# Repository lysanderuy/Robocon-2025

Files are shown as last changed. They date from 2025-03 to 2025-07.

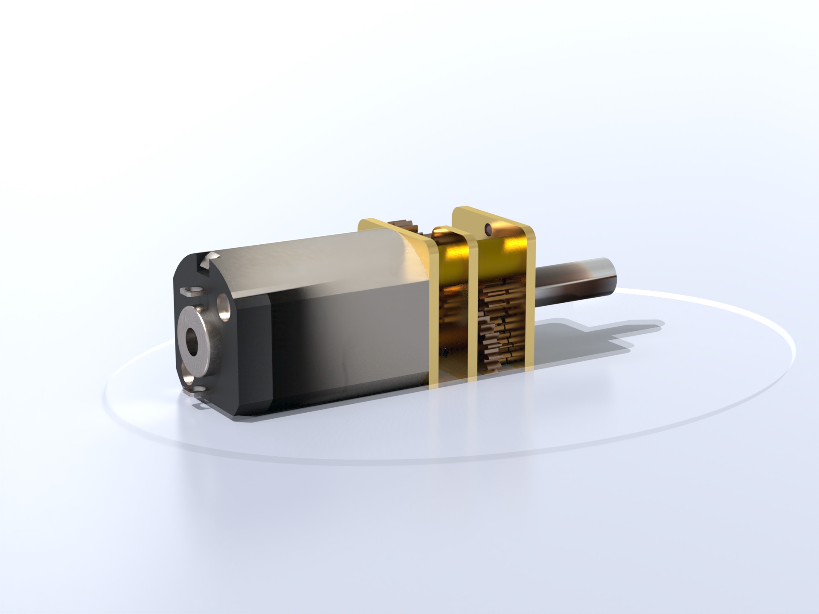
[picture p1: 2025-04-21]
Hardware/3D Parts/Resources/N20/Frame000030.jpg

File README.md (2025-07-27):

USC Robocon-2025 - Robotics Competition (Line Following)

3a6d7730-8ca0-4b9e-8f9a-050f49969c4d
ca18deb3-35a7-4179-8dc5-667313551d99
816b7f0a-6069-4234-8627-e5fa5dca911e

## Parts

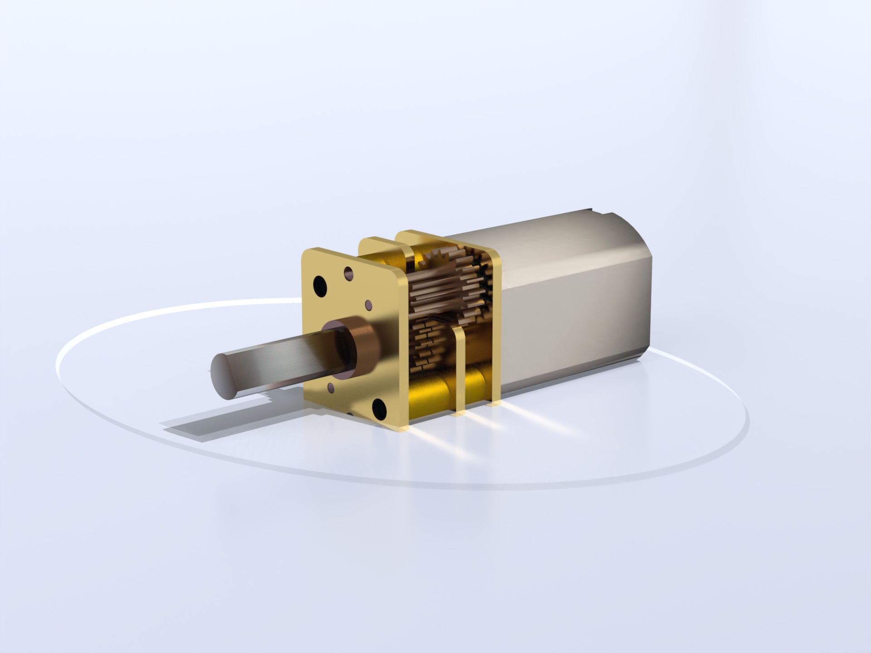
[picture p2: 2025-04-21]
Hardware/3D Parts/Resources/N20/Frame000005.jpg

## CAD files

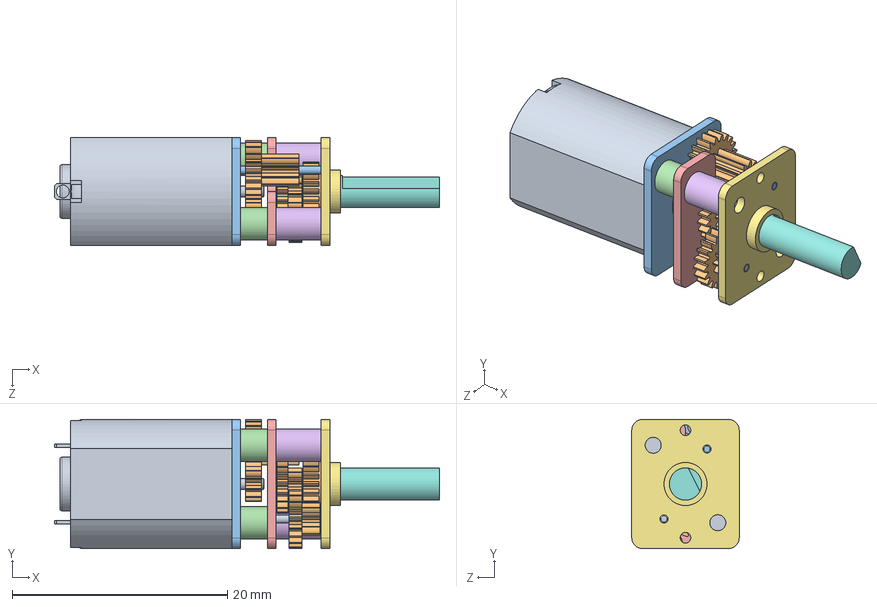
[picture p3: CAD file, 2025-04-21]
Hardware/3D Parts/Resources/N20/Мотор с шестеней.SLDASM
35.8 x 12.0 x 10.0 mm
мотор
spur gear_iso x 8
нижняя пластина редуктора
малая фтулка x 2
средняя пластина редуктора
большая фтулка x 2
верхняя пластина редуктора
вал
втулка шестерни
втулка центральной шестерни
втулка боковой шестерни

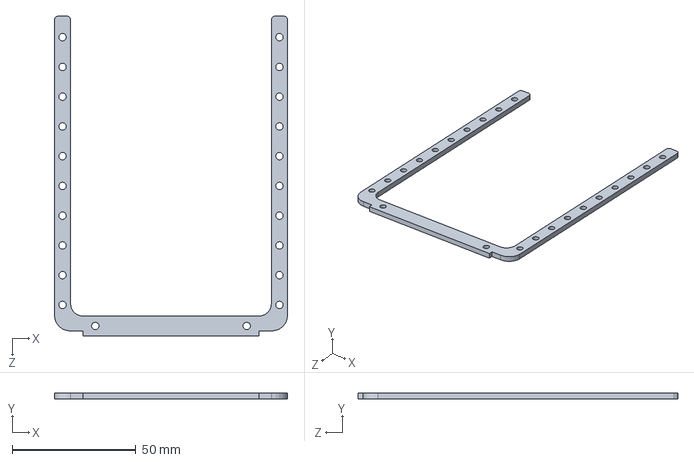
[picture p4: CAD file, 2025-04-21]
Hardware/3D Parts/Mount Rack/mountRack_v1.1.SLDPRT
94.0 x 2.50 x 129.0 mm

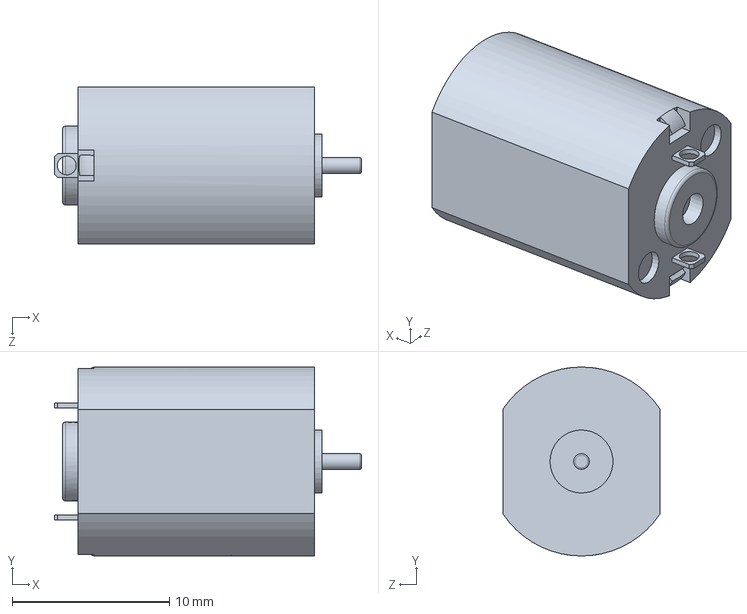
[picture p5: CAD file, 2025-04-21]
Hardware/3D Parts/Resources/N20/мотор.SLDPRT
19.5 x 12.0 x 10.0 mm

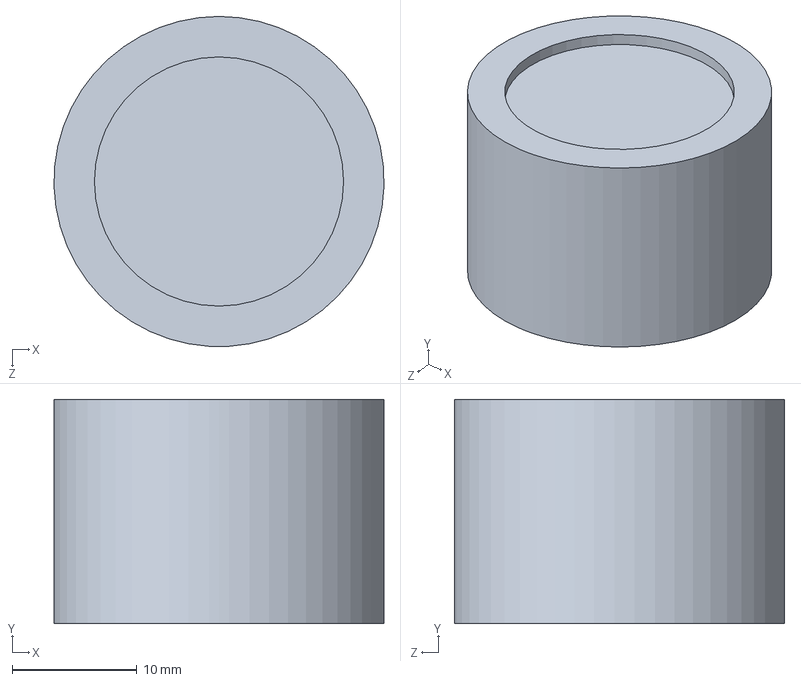
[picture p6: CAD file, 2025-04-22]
Hardware/3D Parts/Wheel/chassisWheel_DHole.SLDPRT
26.5 x 18.0 x 26.5 mm

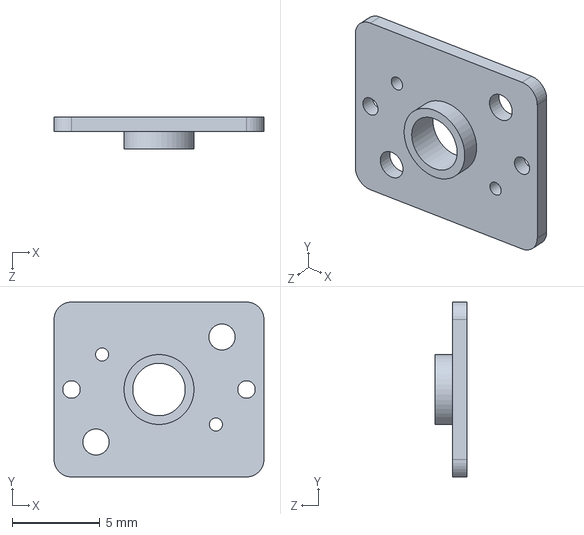
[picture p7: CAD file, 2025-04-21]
Hardware/3D Parts/Resources/N20/верхняя пластина редуктора.SLDPRT
12.0 x 10.0 x 1.80 mm

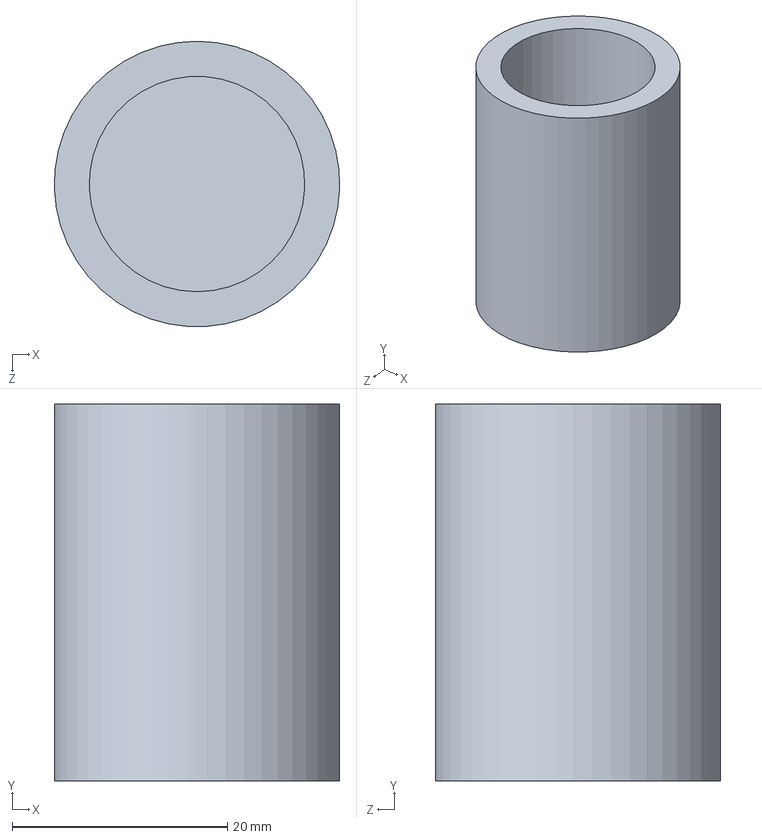
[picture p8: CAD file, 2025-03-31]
Hardware/3D Parts/Wheel/chassisWheel_OHole.SLDPRT
26.5 x 35.0 x 26.5 mm

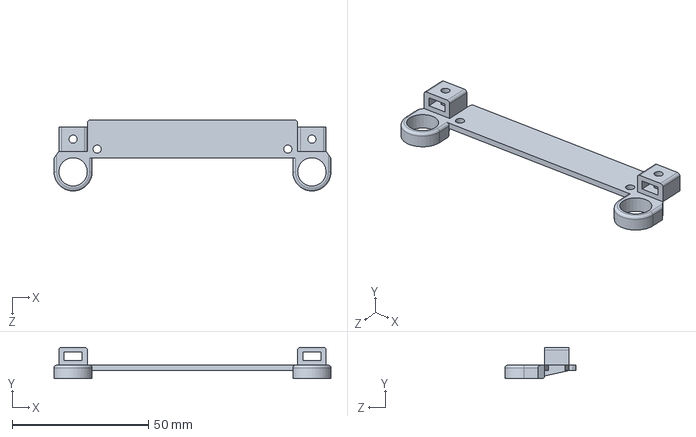
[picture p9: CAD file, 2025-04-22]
Hardware/3D Parts/Mount/sensorcaster_Mount_v1.4.SLDPRT
101.5 x 11.5 x 26.0 mm

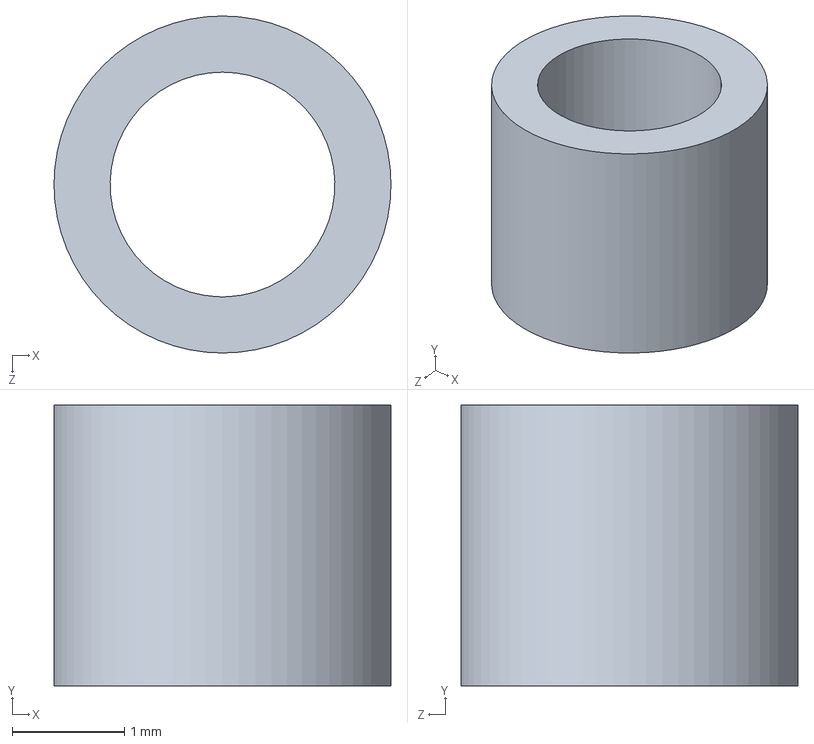
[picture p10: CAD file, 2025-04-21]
Hardware/3D Parts/Resources/N20/малая фтулка.SLDPRT
3.00 x 2.50 x 3.00 mm

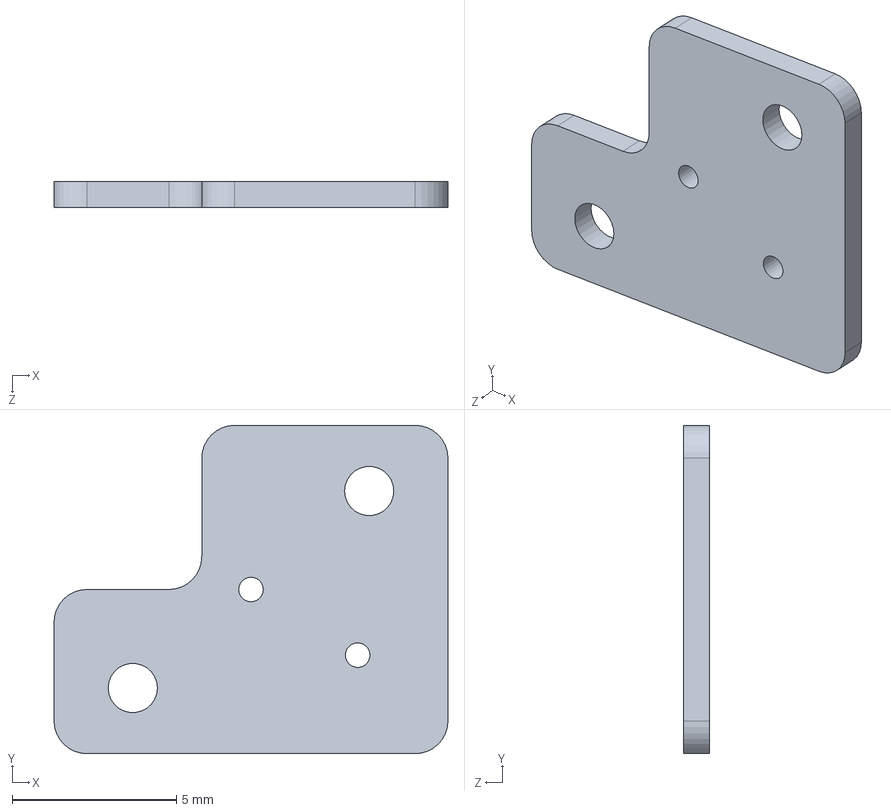
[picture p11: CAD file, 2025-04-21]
Hardware/3D Parts/Resources/N20/средняя пластина редуктора.SLDPRT
12.0 x 10.0 x 0.8 mm

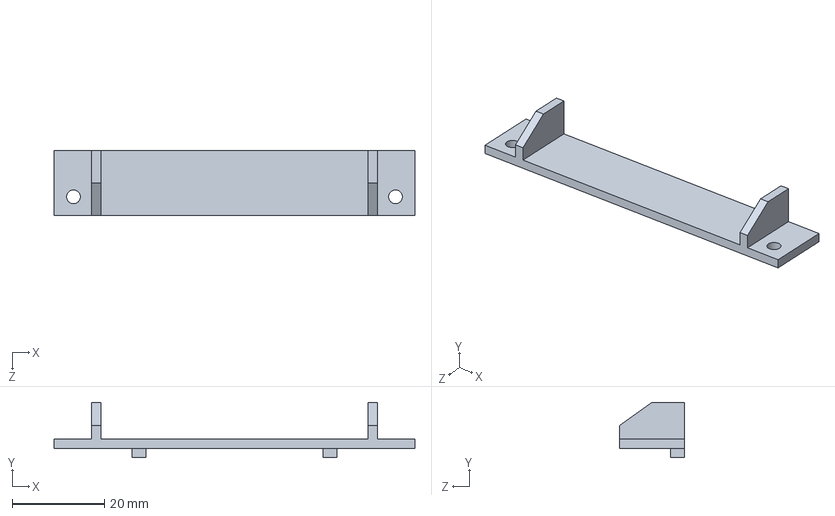
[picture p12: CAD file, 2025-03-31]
Hardware/3D Parts/Mount/sensorHolder.SLDPRT
78.3 x 12.0 x 14.0 mm

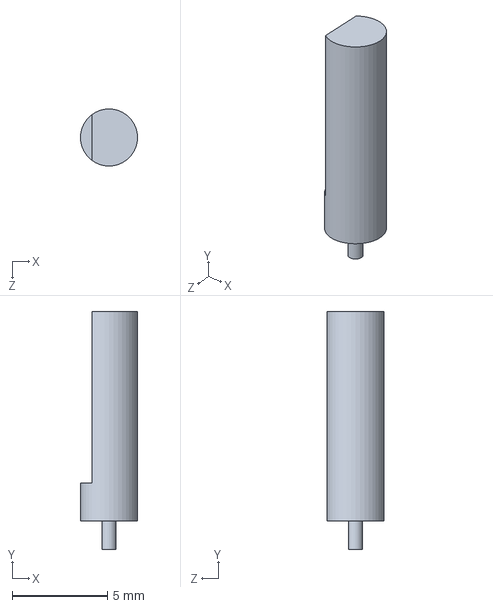
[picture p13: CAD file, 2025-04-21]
Hardware/3D Parts/Resources/N20/вал.SLDPRT
3.00 x 12.5 x 3.00 mm

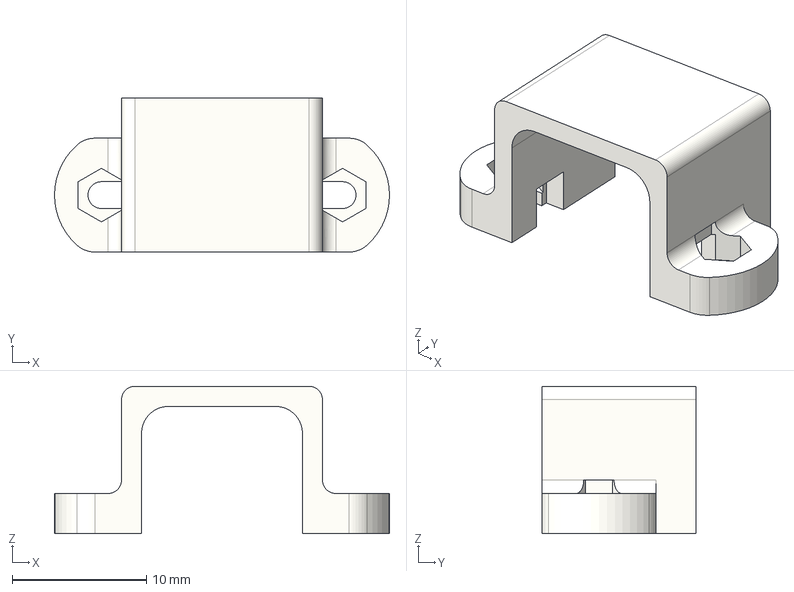
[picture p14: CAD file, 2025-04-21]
Hardware/3D Parts/Resources/N20/Bracket.step
25.0 x 11.5 x 11.0 mm

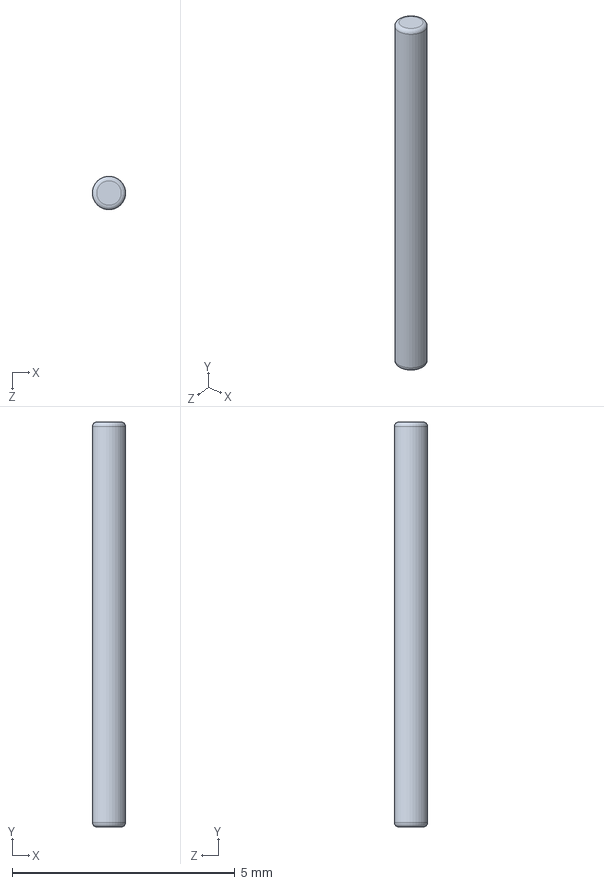
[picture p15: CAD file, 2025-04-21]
Hardware/3D Parts/Resources/N20/втулка боковой шестерни.SLDPRT
0.747 x 9.10 x 0.75 mm

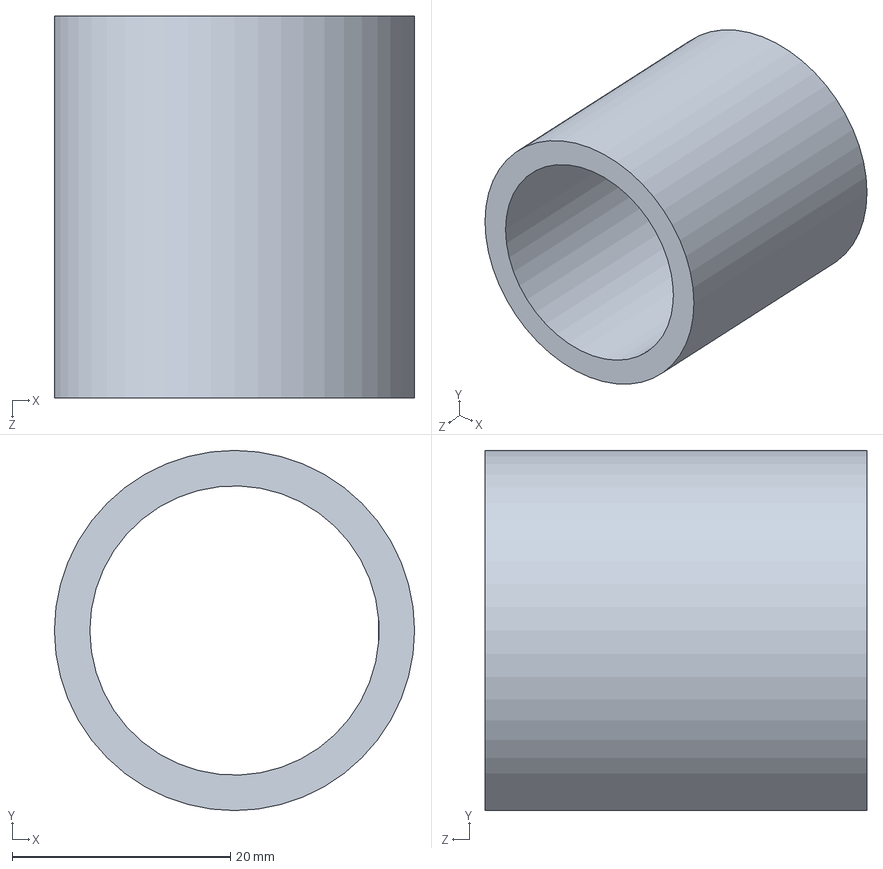
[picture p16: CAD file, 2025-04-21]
Hardware/3D Parts/Resources/N20/siliconTire.SLDPRT
33.0 x 33.0 x 35.0 mm

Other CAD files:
Hardware/3D Parts/Resources/N20/втулка центральной шестерни.SLDPRT
Hardware/3D Parts/Resources/N20/втулка шестерни.SLDPRT
Hardware/3D Parts/Resources/N20/нижняя пластина редуктора.SLDPRT
Hardware/3D Parts/Resources/N20/большая фтулка.SLDPRT
Hardware/3D Parts/Mount Rack/mountRack_v1.0.SLDPRT
Hardware/3D Parts/Mount/sensorcaster_Mount_v1.0.SLDPRT
Hardware/3D Parts/Mount/sensorcaster_Mount_v1.1.SLDPRT
Hardware/3D Parts/Mount/sensorcaster_Mount_v1.2.SLDPRT
Hardware/3D Parts/Mount/sensorcaster_Mount_v1.3.SLDPRT
Hardware/3D Parts/Resources/N20/Bracket.f3d

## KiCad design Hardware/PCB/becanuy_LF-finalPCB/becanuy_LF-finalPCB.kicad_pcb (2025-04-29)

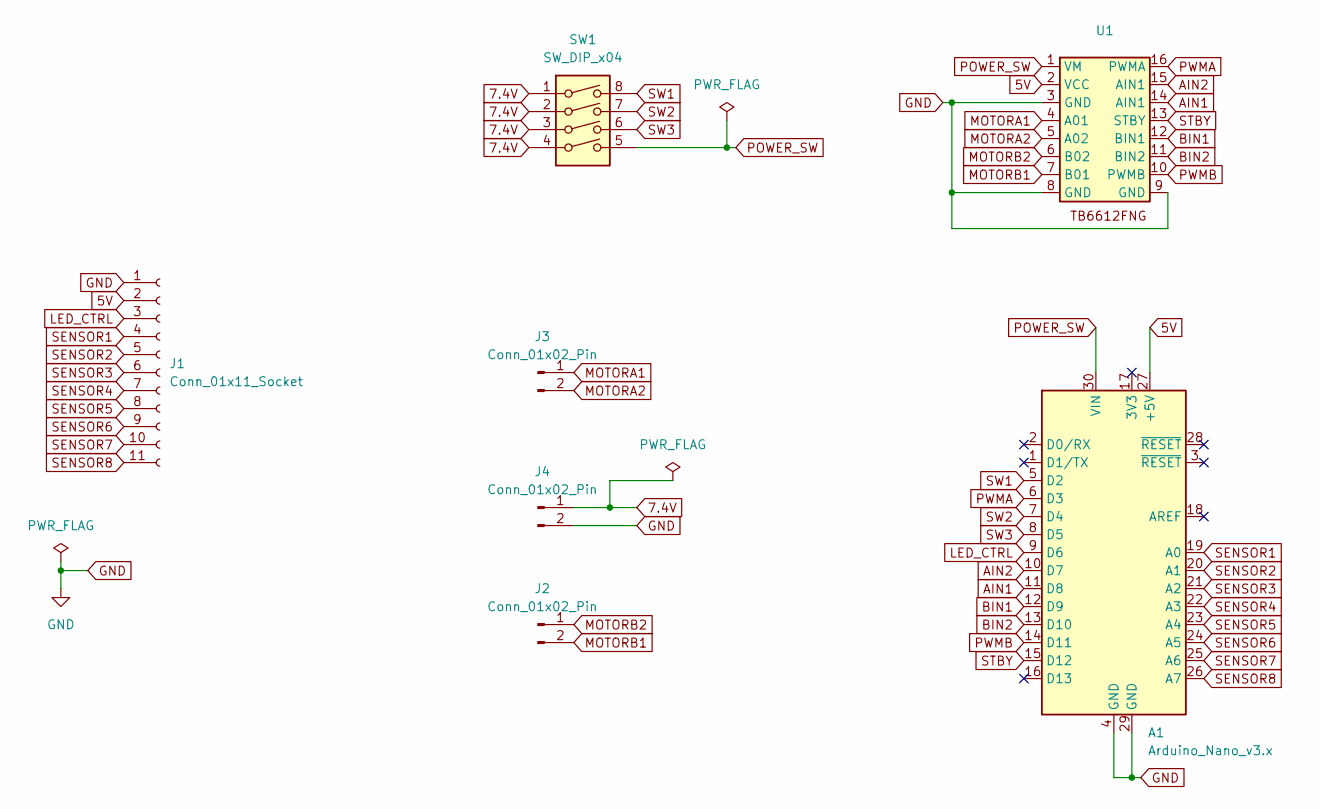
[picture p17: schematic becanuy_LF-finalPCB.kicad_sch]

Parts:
A1: Arduino_Nano_v3.x; Arduino_Nano
J1: Conn_01x11_Socket; PinHeader_1x11_P2.54mm_Vertical
J2, J3, J4: Conn_01x02_Pin; JST_XH_B2B-XH-A_1x02_P2.50mm_Vertical
SW1: SW_DIP_x04; SW_DIP_SPSTx04_Slide_9.78x12.34mm_W7.62mm_P2.54mm
U1: TB6612FNG

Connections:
5V: A1.27 (+5V), J1.2, U1.2 (VCC)
7.4V: J4.1, SW1.1, SW1.2, SW1.3, SW1.4
AIN1: A1.11 (D8), U1.14 (AIN1)
AIN2: A1.10 (D7), U1.15 (AIN1)
BIN1: A1.12 (D9), U1.12 (BIN1)
BIN2: A1.13 (D10), U1.11 (BIN2)
GND: A1.4 (GND), A1.29 (GND), J1.1, J4.2, U1.3 (GND), U1.8 (GND), U1.9 (GND)
LED_CTRL: A1.9 (D6), J1.3
MOTORA1: J3.1, U1.4 (A01)
MOTORA2: J3.2, U1.5 (A02)
MOTORB1: J2.2, U1.7 (B01)
MOTORB2: J2.1, U1.6 (B02)
POWER_SW: A1.30 (VIN), SW1.5, U1.1 (VM)
PWMA: A1.6 (D3), U1.16 (PWMA)
PWMB: A1.14 (D11), U1.10 (PWMB)
SENSOR1: A1.19 (A0), J1.4
SENSOR2: A1.20 (A1), J1.5
SENSOR3: A1.21 (A2), J1.6
SENSOR4: A1.22 (A3), J1.7
SENSOR5: A1.23 (A4), J1.8
SENSOR6: A1.24 (A5), J1.9
SENSOR7: A1.25 (A6), J1.10
SENSOR8: A1.26 (A7), J1.11
STBY: A1.15 (D12), U1.13 (STBY)
SW1: A1.5 (D2), SW1.8
SW2: A1.7 (D4), SW1.7
SW3: A1.8 (D5), SW1.6

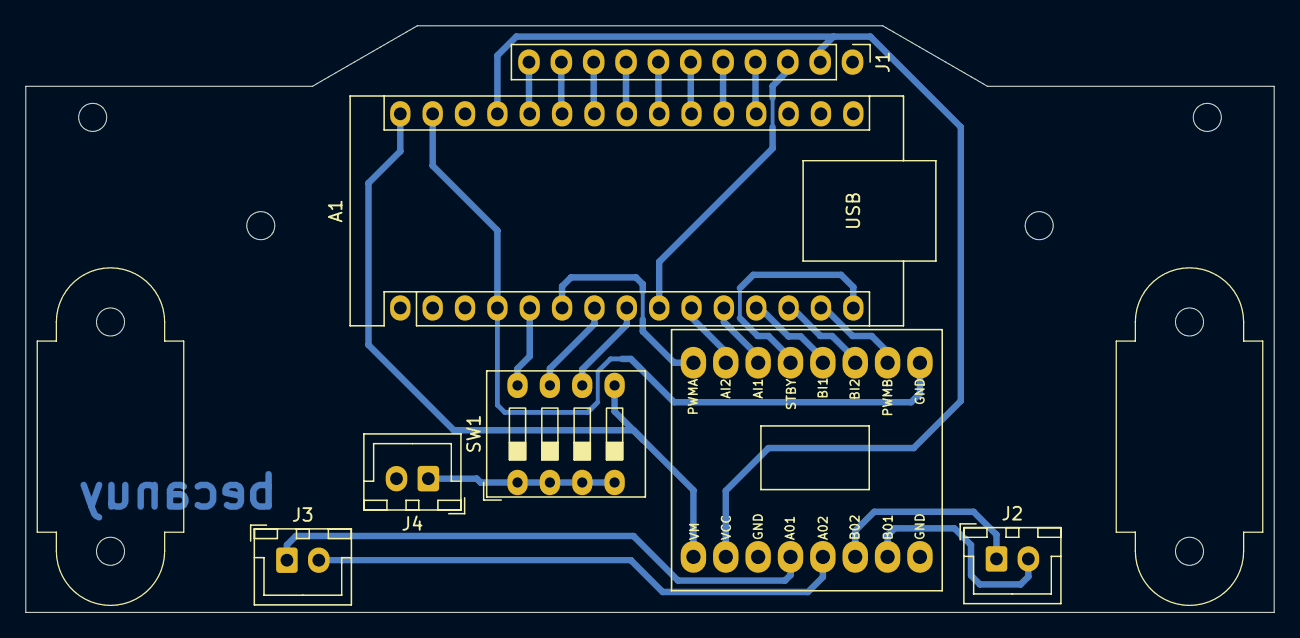
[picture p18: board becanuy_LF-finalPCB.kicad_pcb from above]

Board: 2 copper layers, 98.0 x 46.0 mm, 7 parts (0 on the bottom side), 27 nets.

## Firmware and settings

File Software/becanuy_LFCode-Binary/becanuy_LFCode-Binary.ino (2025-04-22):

#include <QTRSensors.h>
#include <SparkFun_TB6612.h>

// // DIP Switch pin assignments
// #define SW0 
// #define SW1
// #define SW2

// QTR 8A pin assignments
#define SENSOR8 A7
#define SENSOR7 A6
#define SENSOR6 A5
#define SENSOR5 A4
#define SENSOR4 A3
#define SENSOR3 A2
#define SENSOR2 A1
#define SENSOR1 A0
#define LED_CTRL 6

// TB6612FNG pin assignments
#define PWMA 3
#define PWMB 11
#define AIN2 7
#define AIN1 8
#define BIN1 9
#define BIN2 10
#define STBY 12

// Sensor setup
const int sensorCount = 8;
const uint8_t sensorArray[sensorCount] = { SENSOR8, SENSOR7, SENSOR6, SENSOR5, SENSOR4, SENSOR3, SENSOR2, SENSOR1 };
uint16_t sensorValues[sensorCount];
QTRSensors qtr;

// Calibration variables
const int ledPin = LED_BUILTIN;
int ledState = LOW;
String direction = " ";
bool onWhite = false;
static int sensorThreshold[sensorCount];

// Motor setup
Motor leftMotor = Motor(AIN1, AIN2, PWMA, 1, STBY);
Motor rightMotor = Motor(BIN1, BIN2, PWMB, 1, STBY);

// Speed Variables
const float speedMultiplierL = 1;
const float speedMultiplierR = 1;
const int baseSpeed = 80; // Straight
const int slightHSpeed = 80; // Slight High
const int slightLSpeed = 65; // Slight Low
const int moderateHSpeed = 90; // Moderate High
const int moderateLSpeed = 45; // Moderate Low
const int hardHSpeed = 255; // Hard High
const int hardLSpeed = -255; // Hard Low

void setup() {
  Serial.begin(9600);

  qtr.setTypeAnalog();
  qtr.setSensorPins(sensorArray, sensorCount);

  pinMode(ledPin, OUTPUT);
  pinMode(LED_CTRL, OUTPUT);
  digitalWrite(LED_CTRL, HIGH);
  delay(10);

  noCalibration();
  delay(2000);
}

void loop() {
  qtr.read(sensorValues);

  followLine1();

  // displayReadings(sensorValues, 'A');
  // displayReadings(sensorValues, 'D');
}

//======================================vvvLINE FOLLOWING FUNCTIONSvvv======================================//
void followLine1() {
  int position=0;
  int first, second, third, fourth, fifth, sixth, seventh, eighth;

  first = (sensorValues[0] > sensorThreshold[0]) ? 1 : 0;
  second = (sensorValues[1] > sensorThreshold[1]) ? 1 : 0;
  third = (sensorValues[2] > sensorThreshold[2]) ? 1 : 0;
  fourth = (sensorValues[3] > sensorThreshold[3]) ? 1 : 0;
  fifth = (sensorValues[4] > sensorThreshold[4]) ? 1 : 0;
  sixth = (sensorValues[5] > sensorThreshold[5]) ? 1 : 0;
  seventh = (sensorValues[6] > sensorThreshold[6]) ? 1 : 0;
  eighth = (sensorValues[7] > sensorThreshold[7]) ? 1 : 0;

  int sensorReadings[sensorCount] = { first, second, third, fourth, fifth, sixth, seventh, eighth };

  if ((sensorReadings[0] == 1 && sensorReadings[7] == 1 && (sensorReadings[3] == 0 || sensorReadings[4] == 0))) { 
    onWhite = true;
  }
  else if ((sensorReadings[0] == 0 && sensorReadings[7] == 0 && (sensorReadings[3] == 1 || sensorReadings[4] == 1))) {
    onWhite = false;
  }
 
  if (onWhite) {
    for (int i=0 ; i<sensorCount ; i++) {
      sensorReadings[i] = (sensorReadings[i] == 0) ? 1 : 0;
    }
  }
  
  for (int i = 0; i < sensorCount; i++) {
    position |= sensorReadings[i] << (7 - i);
  }
  
  switch (position) {
    //============ Straight Cases ============
    case 0b00111100:
    case 0b01111110:
    case 0b11111111:
    case 0b00000000:
      Straight();
      direction = "Straight";
      break;
    //=========== Slight Left Cases ===========
    case 0b01111000:
    case 0b01111100:
    case 0b00110000:
    case 0b00010000:
    case 0b01110000:
      slightLeft();
      direction = "Slight Left";
      break;
    //=========== Slight Right Cases ===========
    case 0b00011110:
    case 0b00111110:
    case 0b00001100:
    case 0b00001000:
    case 0b00011100:
      slightRight();
      direction = "Slight Right";
      break;
    //========== Moderate Left Cases ==========11110000
    case 0b11100000:
    case 0b11111000:
    case 0b00111000:
    case 0b01100000:
    case 0b11111100:
    case 0b11111110:
    case 0b00100000:
      moderateLeft();
      direction = "Moderate Left";
      break;
    //========= Moderate Right Cases =========
    case 0b00001111:
    case 0b00000111:
    case 0b00011111:
    case 0b00001110:
    case 0b00000110:
    case 0b00000100:
    case 0b00111111:
    case 0b01111111:
      moderateRight();
      direction = "Moderate Right";
      break;
    //============ Hard Left Cases ============
    case 0b11000000:
    case 0b10000000:
    case 0b01000000:
      hardLeft();
      direction = "Hard Left";
      break;
    //=========== Hard Right Cases ===========
    case 0b00000011:
    case 0b00000001:
    case 0b00000010:
      hardRight();
      direction = "Hard Right";
      break;
    //================= Default =================
    default:
      break;
  }
}
//======================================vvvLINE FOLLOWING FUNCTIONSvvv======================================//

//======================================vvvCALIBRATIONS FUNCTIONSvvv======================================//
void noCalibration() {
  stop();

  for (int i=0 ; i<sensorCount ; i++) {
    sensorThreshold[i] = 140;
  }

  delay(500);
}

void calibrateSensors() {
  Serial.println(">>> Calibrating QTR sensors...");
  stop();  

  for (int i = 0; i < 200; i++) {
    qtr.calibrate();  
    if (i < 100) {
      runMotors(80, -80);
    }
    else {
      runMotors(-80, 80);
    }              
    delay(10);
  }

  stop();
  Serial.println(">>> Calibration complete.");

  for (uint8_t i = 0; i < sensorCount; i++) {
    int mn = qtr.calibrationOn.minimum[i];
    int mx = qtr.calibrationOn.maximum[i];
    sensorThreshold[i] = (mn + mx) / 2;

    Serial.print("S"); Serial.print(i);
    Serial.print(": min="); Serial.print(mn);
    Serial.print(" max="); Serial.print(mx);
    Serial.print(" thr="); Serial.println(sensorThreshold[i]);
  }

  blinkLED();  
}

void blinkLED() {
  for (int i = 0; i < 3; i++) {
    digitalWrite(ledPin, HIGH);
    delay(500);
    digitalWrite(ledPin, LOW);
    delay(500);
  }
}
//======================================^^^CALIBRATIONS FUNCTIONS^^^======================================//

//======================================vvvSENSOR FUNCTIONSvvv======================================//
void displayReadings(int* sensorReadings, char type) {
  if (type == 'A') {
    int val_8 = sensorReadings[0];
    int val_7 = sensorReadings[1];
    int val_6 = sensorReadings[2];
    int val_5 = sensorReadings[3];
    int val_4 = sensorReadings[4];
    int val_3 = sensorReadings[5];
    int val_2 = sensorReadings[6];
    int val_1 = sensorReadings[7];

    Serial.print("8: ");
    Serial.print(val_8);
    Serial.print("\t");
    Serial.print("7: ");
    Serial.print(val_7);
    Serial.print("\t");
    Serial.print("6: ");
    Serial.print(val_6);
    Serial.print("\t");
    Serial.print("5: ");
    Serial.print(val_5);
    Serial.print("\t");
    Serial.print("4: ");
    Serial.print(val_4);
    Serial.print("\t");
    Serial.print("3: ");
    Serial.print(val_3);
    Serial.print("\t");
    Serial.print("2: ");
    Serial.print(val_2);
    Serial.print("\t");
    Serial.print("1: ");
    Serial.print(val_1);
  } 
  else if (type == 'D') {
    int first = (sensorReadings[0] > sensorThreshold[0]) ? 1 : 0;
    int second = (sensorReadings[1] > sensorThreshold[1]) ? 1 : 0;
    int third = (sensorReadings[2] > sensorThreshold[2]) ? 1 : 0;
    int fourth = (sensorReadings[3] > sensorThreshold[3]) ? 1 : 0;
    int fifth = (sensorReadings[4] > sensorThreshold[4]) ? 1 : 0;
    int sixth = (sensorReadings[5] > sensorThreshold[5]) ? 1 : 0;
    int seventh = (sensorReadings[6] > sensorThreshold[6]) ? 1 : 0;
    int eighth = (sensorReadings[7] > sensorThreshold[7]) ? 1 : 0;

    Serial.print("8: ");
    Serial.print(first);
    Serial.print("\t");
    Serial.print("7: ");
    Serial.print(second);
    Serial.print("\t");
    Serial.print("6: ");
    Serial.print(third);
    Serial.print("\t");
    Serial.print("5: ");
    Serial.print(fourth);
    Serial.print("\t");
    Serial.print("4: ");
    Serial.print(fifth);
    Serial.print("\t");
    Serial.print("3: ");
    Serial.print(sixth);
    Serial.print("\t");
    Serial.print("2: ");
    Serial.print(seventh);
    Serial.print("\t");
    Serial.print("1: ");
    Serial.print(eighth);
  }

  Serial.print("\t");
  Serial.print("D: ");
  Serial.print(direction);

  Serial.println();
}

void displayThresholds() {
  for (int i=0 ; i<sensorCount ; i++) {
    Serial.print("t");
    Serial.print(8 - i);
    Serial.print(": ");
    Serial.print(sensorThreshold[i]);
    Serial.print("\t");
  }

  Serial.println();
}
//======================================^^^SENSOR FUNCTIONS^^^======================================//

//======================================vvvCUSTOM MOTOR FUNCTIONSvvv======================================//
void runMotors(int left, int right) {
  leftMotor.drive(speedMultiplierL * left);
  rightMotor.drive(speedMultiplierR * right);
}

void stop() {
  leftMotor.drive(0);
  rightMotor.drive(0);
}

void spinRight(int speed) {
  leftMotor.drive(speed);
  rightMotor.drive(-1 * speed);
}

void spinLeft(int speed) {
  leftMotor.drive(-1 * speed);
  rightMotor.drive(speed);
}

void Straight() {
  runMotors(baseSpeed, baseSpeed);
}

void slightLeft() {
  runMotors(slightLSpeed, slightHSpeed);
}

void slightRight() {
  runMotors(slightHSpeed, slightLSpeed);
}

void moderateLeft() {
  runMotors(moderateLSpeed, moderateHSpeed);
}

void moderateRight() {
  runMotors(moderateHSpeed, moderateLSpeed);
}

void hardLeft() {
  runMotors(hardLSpeed, hardHSpeed);
}

void hardRight() {
  runMotors(hardHSpeed, hardLSpeed);
}
//======================================^^^CUSTOM MOTOR FUNCTIONS^^^======================================//

//======================================vvvEMOTE FUNCTIONSvvv======================================//
void emoteOne() {
  runMotors(255, 255);
  delay(500);
  stop();
  delay(300);
  spinLeft(255);
  delay(225);
  stop();
  delay(300);

  runMotors(255, 255);
  delay(500);
  stop();
  delay(300);
  spinLeft(255);
  delay(225);
  stop();
  delay(300);

  runMotors(255, 255);
  delay(500);
  stop();
  delay(300);
  spinLeft(255);
  delay(225);
  stop();
  delay(300);

  runMotors(255, 255);
  delay(500);
  stop();
  delay(300);
  spinLeft(255);
  delay(225);
  stop();
  delay(300);
}
//======================================^^^EMOTE FUNCTIONS^^^======================================//

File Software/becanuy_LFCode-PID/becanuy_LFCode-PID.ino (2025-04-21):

#include <QTRSensors.h>
#include <SparkFun_TB6612.h>

// QTR 8A pin assignments
//#define SENSOR8 A7
#define SENSOR7 A6
#define SENSOR6 A5
#define SENSOR5 A4
#define SENSOR4 A3
#define SENSOR3 A2
#define SENSOR2 A1
//#define SENSOR1 A0
#define LED_CTRL 6  

// TB6612FNG pin assignments
#define PWMA 3
#define PWMB 11
#define AIN2 7
#define AIN1 8
#define BIN1 9
#define BIN2 10

// Motor setup
Motor leftMotor = Motor(AIN2, AIN1, PWMA, 1, 255);
Motor rightMotor = Motor(BIN1, BIN2, PWMB, 1, 255);

// Calibration variables
unsigned long calibrationStartTime = 0; 
const int calibrationDuration = 5000;
const int ledPin = LED_BUILTIN;
int ledState = LOW;
bool calibrationPeriod = false;
int threshold = 0;

// Global sensor arrays
const uint8_t sensorArray[6] = {SENSOR7,  SENSOR6,  SENSOR5, SENSOR4, SENSOR3, SENSOR2};
int sensorValues[6];

// PID Variables
QTRSensors qtr;
int SensorCount = 6;
int position;
float Kp = 0.1;
float Ki = 0.01; 
float Kd = 0.07;
int P, D, I, previousError, PIDvalue, error;
int lsp, rsp;
int tempPosition;
int centerPosition= 2500;
int minSpeed = -145;
int maxSpeed = 145;
int baseSpeed = 145;

void setup() {
  Serial.begin(9600);

  qtr.setSensorPins(sensorArray, SensorCount);

  digitalWrite(LED_CTRL, HIGH);
  delay(5);

  noCalibration();
}

void loop() {
  readSensors(sensorValues);

  position = qtr.readLineBlack(sensorValues);
  error = centerPosition - position;

  P = error;
  I = constrain(I + error, minSpeed, maxSpeed);
  D = error - previousError;
  previousError = error;

  int motorSpeed = (Kp * P) + (Ki * I) + (Kd * D);

  // baseSpeed = 140 + 20*sin(2*M_PI*10*millis()/1000);

  int leftSpeed = constrain((baseSpeed - motorSpeed), minSpeed, maxSpeed);
  int rightSpeed = constrain((baseSpeed + motorSpeed), minSpeed, maxSpeed);

  leftMotor.drive(leftSpeed);
  rightMotor.drive(rightSpeed);
}

//======================================vvvCALIBRATIONS FUNCTIONSvvv======================================//
void noCalibration() {
  threshold = 200;

  slightForward(150);
  delay(500);
}

void calibrateSensors() {
  if (!calibrationPeriod) {
    stop();

    int arrayThreshold[6] = { SENSOR7,  SENSOR6,  SENSOR5, SENSOR4, SENSOR3, SENSOR2};
    int indexThreshold = 0;
    
    for (int i = 0 ; i < 6 ; i ++) {
      if (arrayThreshold[i] < arrayThreshold[indexThreshold]) 
        indexThreshold = i;
    }

    threshold = arrayThreshold[indexThreshold] + 250;
  }
  
  blinkLED();
}

void blinkLED() {
  for (int i = 0; i < 3; i++) {
    digitalWrite(ledPin, HIGH);   
    delay(500);                  
    digitalWrite(ledPin, LOW);    
    delay(500);                   
  }
}
//======================================^^^CALIBRATIONS FUNCTIONS^^^======================================//

//======================================vvvSENSOR FUNCTIONSvvv======================================//
void readSensors (int* sensorVal) {
  for (int i=0 ; i<6 ; i++) {
    sensorVal[i] = analogRead(sensorArray[i]);
  }
}

void displayReadings (int* sensorReadings, int position, int error) {
  //int val_8 = sensorReadings[0];  
  int val_7 = sensorReadings[1];          
  int val_6 = sensorReadings[2];    
  int val_5 = sensorReadings[3];       
  int val_4 = sensorReadings[4];         
  int val_3 = sensorReadings[5];      
  int val_2 = sensorReadings[6];       
  //int val_1 = sensorReadings[7];

  Serial.print("\t");
  Serial.print("8: ");
  //Serial.print(val_8);
  Serial.print("\t");
  Serial.print("7: ");
  Serial.print(val_7);
  Serial.print("\t");
  Serial.print("6: ");
  Serial.print(val_6);
  Serial.print("\t");
  Serial.print("5: ");
  Serial.print(val_5);
  Serial.print("\t");
  Serial.print("4: ");
  Serial.print(val_4);
  Serial.print("\t");
  Serial.print("3: ");
  Serial.print(val_3);
  Serial.print("\t");
  Serial.print("2: ");
  Serial.print(val_2);
  Serial.print("\t");
  Serial.print("1: ");
  //Serial.print(val_1);
  Serial.print("\t");
  Serial.print("POS: ");
  Serial.print(position);
  Serial.print("\t");
  Serial.print("ERR: ");
  Serial.print(error);

  Serial.println();
}
//======================================^^^SENSOR FUNCTIONS^^^======================================//

//======================================vvvCUSTOM MOTOR FUNCTIONSvvv======================================//
void stop() {
  leftMotor.drive(0);
  rightMotor.drive(0);
}

void slightForward(int speed) {
    leftMotor.drive(speed);
    rightMotor.drive(speed);
}

void spinRight() {
  leftMotor.drive(255);
  rightMotor.drive(-255);
}

void spinLeft() {
  leftMotor.drive(-255);
  rightMotor.drive(255);
}
//======================================^^^CUSTOM MOTOR FUNCTIONS^^^======================================//

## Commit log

2025-03-31 Design 3D model for sensor mount and rack
    [assemblyTest.SLDASM, chassisWheel.SLDPRT, mountRack.SLDPRT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]
2025-04-21 Update: Software and Hardware
    [Bracket.f3d, Bracket.step, QTR8A_sensorCases.xlsx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]
2025-04-22 Create: Multiple LF Logic
    [QTR8A_sensorCases.xlsx, chassisWheel_DHole.SLDPRT, chassisWheel_OHole.SLDPRT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]
2025-04-29 Add: final PID code with switching speed modes
2025-04-29 Add: Final PCB design and schematic
    [becanuy_LF-finalPCB.kicad_pcb, becanuy_LF-finalPCB.kicad_sch]
